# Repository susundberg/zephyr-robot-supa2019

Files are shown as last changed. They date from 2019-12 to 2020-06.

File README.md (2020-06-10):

# zephyr-robot-supa2019
Zephyr based robot

For pictures and some details see [Hackaday.io](https://hackaday.io/project/170682-lawm-mowing-robot-with-stm32-blue-pill-and-zephyr)

## Pinout

Motor related

**Motor1 - left**

| Function | Pin | Info  |
| --- | --- | --- |
| Hal input | PA12 - TIM1_ETR | (yel) |
| Motor Control A | PB12 - DOUT | (yel) -> (Pin 9 on motor) |
| Motor Control B | PB13 - DOUT | (ora) -> (Pin 8 on motor) |
| Motor PWM | PA6 - TIM3_CH1  | (red) -> (Pin 10 on motor) |
| Bumber 1 | PA11 - ISR11 | (red) |

**Motor2 - right**

| Function | Pin | Info  |
| --- | --- | ----- |
| Hal input | PA0  - TIM2_ETR  | (ora) |
| Motor Control A | PB14 - DOUT | (red) -> (Pin 9 on motor) |
| Motor Control B | PB15 - DOUT | (gre) -> (Pin 8 on motor) |
| Motor PWM | PA7  - TIM3_CH2  | (blu) |
| Bumber 2 | PA8 - ISR8 | (blue) |

**Other**

| Function | Pin | Info  |
| --- | ---  | ----- |
| UART1-TX |  PA9 | (gre) |
| UART1-RX |  PA10 | (yel) |
| Imu I2C | PB7 - I2C1_SDA | |
| Imu I2C | PB6 - I2C1_SCL | |
| Imu isr | PB5 - ISR5 | |
| UI IR RCV |  PB3 - ISR3 | |  
| UI SW1 |  PA2 - ISR2 | |
| UI SW0 |  PA1 - ISR1 | |  
| UI LD0 |  PC13 | System led + UI led 0 | 
| UI LD1 |  PC14 | UI led 1- TODO (max sink 3ma!) |

**Big motor**

| Function | Pin | Info | Notes | 
| ---  | --- | --- | --- |
| Big Enable | PB8 - TIM4_CH3 PWM  | (ora) | Now only GPIO |
| Big current meas | PA3 - ADC1-3 | | TODO NOT CONN |
| Battery volt meas| PA4 - ADC1-4 | | TODO NOT CONN |

## Motor control

Robotdyn shield: https://robotdyn.com/motor-shield-2a-l298p-2-motors-for-arduino.html

| Function | A  |  B | PWM  |
| --- | -- | -- | ---  |
| Forward | 1  | 0  |  X |
| Backward | 0  | 1  |  X |
| Force stop | 1  | 1  |  1 |
| Free roll | 0  | 0  |  0 |

## Program cable in MK1

In programmer side:
* Yellow
* Orange
* Green (GND)

## Would next time do differently:

1. Make proto PCB rather than wire mess. Even better, plan and order PCB.
1. Add reset to Bluetooth HC-05 - it seems to buffer some shit from zephyr.
1. Add external reset to other chips?
1. While blingking leds are great, they provide quite little information. Uart over bluetooth is good, not great. Super project would have android app that would be able to show some specific values -- for example uart lines in format of: DATA:<name>:value;
1. If using STM32 boards, the Nucleo boards are cheap and contain programmer. The STM32 blue pill is cheap, works, but the reset is not working well. Booting to stm32 bootloader with program makes it work (but it does not work if cpu is messed up).

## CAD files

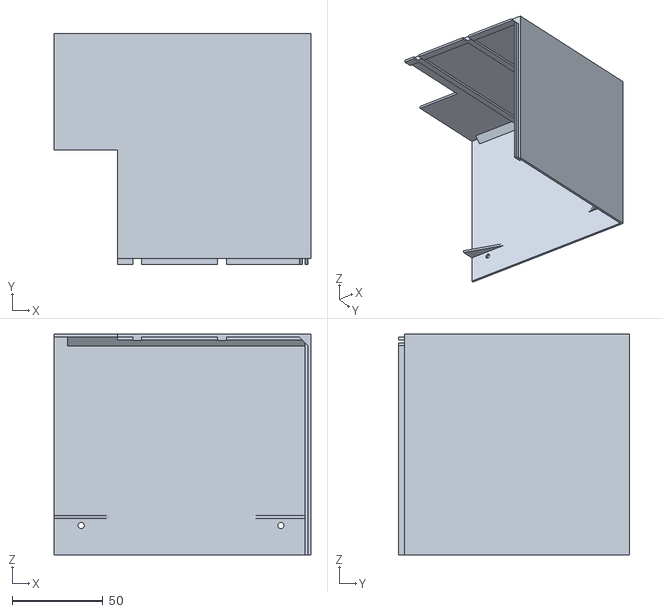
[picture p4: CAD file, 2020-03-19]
3d_parts/stl_files/rcover_ba_ri_v0.stl
141.6 x 127.3 x 121.6

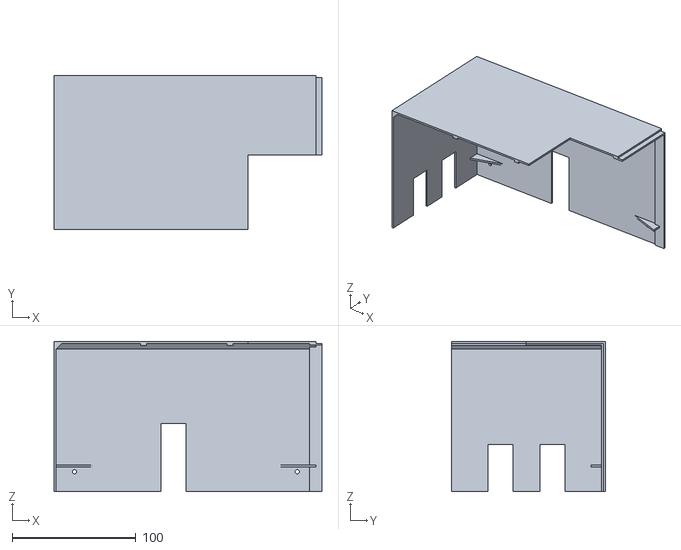
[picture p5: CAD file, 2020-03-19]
3d_parts/stl_files/rcover_fr_le_v0.stl
216.6 x 124.1 x 121.6

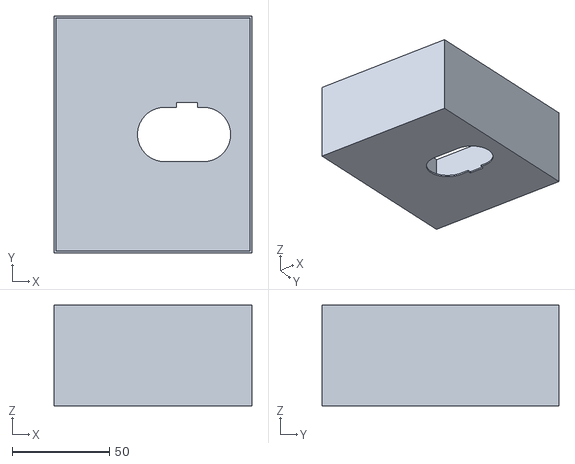
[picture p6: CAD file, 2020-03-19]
3d_parts/stl_files/rcover_bbox_v0.stl
102.0 x 122.0 x 52.0

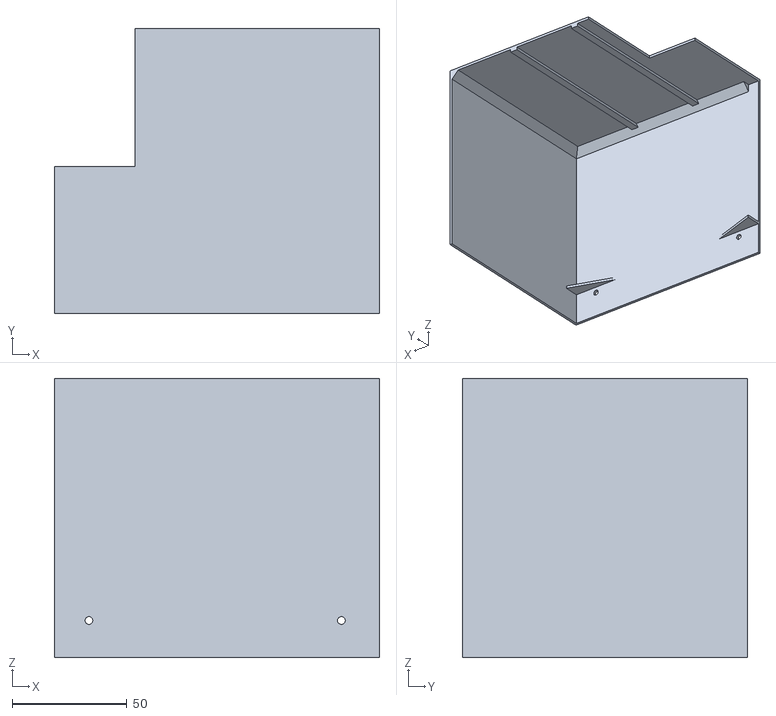
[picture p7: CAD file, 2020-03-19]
3d_parts/stl_files/rcover_ba_le_v0.stl
141.6 x 124.1 x 121.6

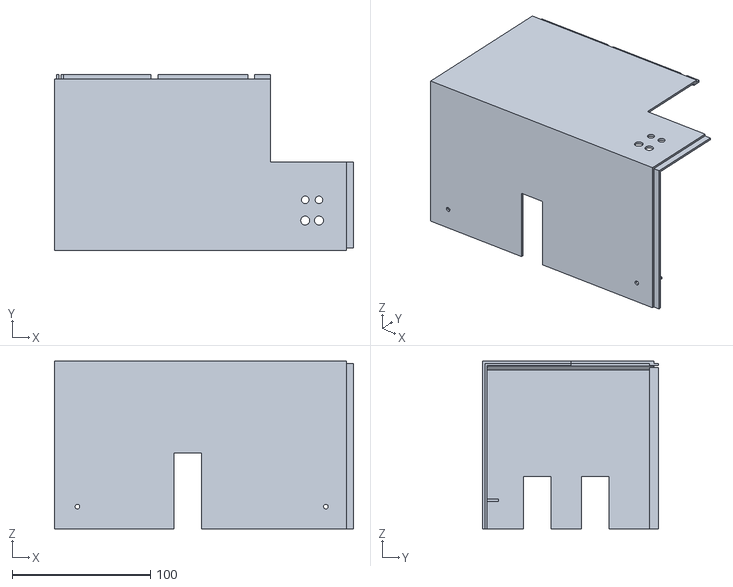
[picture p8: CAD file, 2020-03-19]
3d_parts/stl_files/rcover_fr_ri_v1.stl
216.6 x 127.3 x 121.6

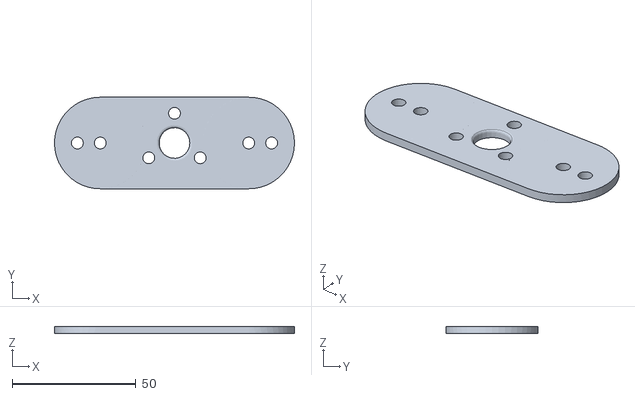
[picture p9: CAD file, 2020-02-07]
3d_parts/stl_files/robot_mower_blade_v0.stl
97.0 x 37.0 x 3.01

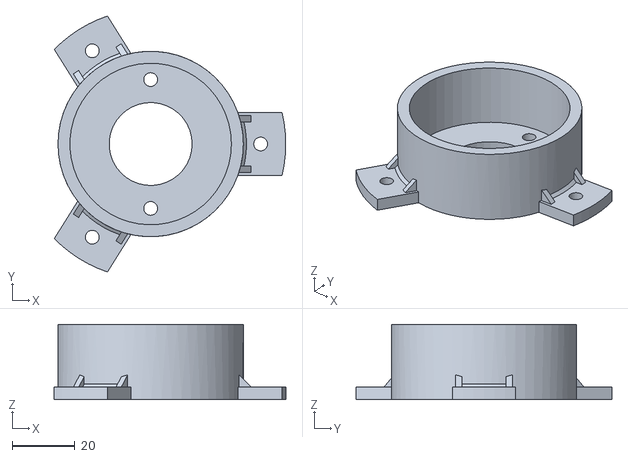
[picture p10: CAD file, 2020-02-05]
3d_parts/stl_files/bmotor_mount_v0.stl
73.7 x 81.5 x 24.0

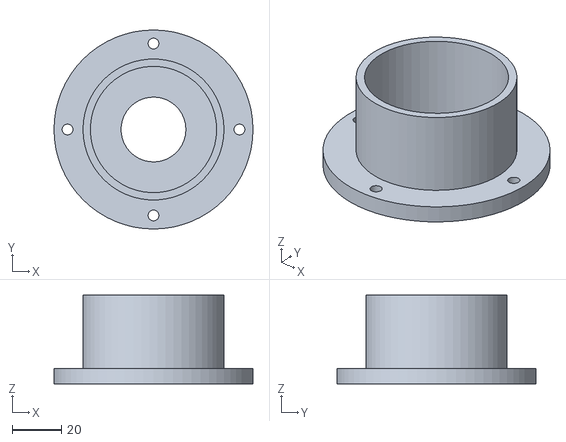
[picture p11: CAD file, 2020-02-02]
3d_parts/stl_files/robot_motor_large_v0.stl
81.0 x 81.0 x 36.2

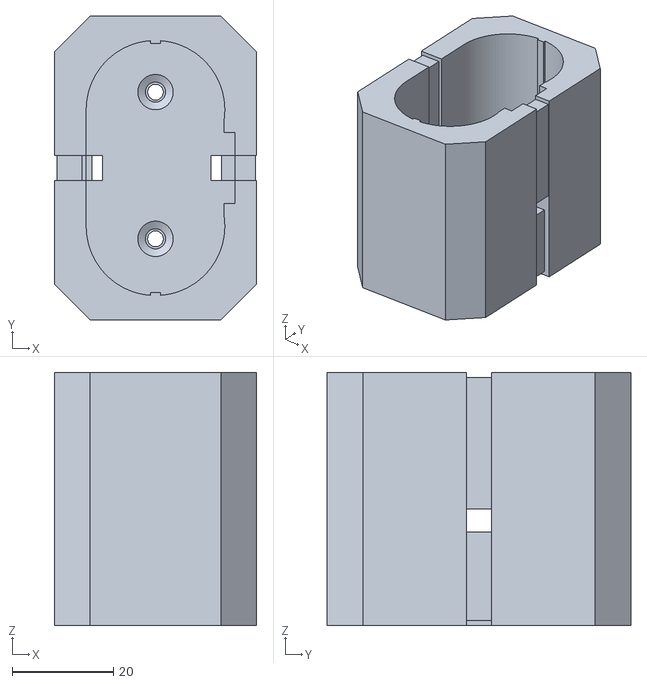
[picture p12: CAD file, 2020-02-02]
3d_parts/stl_files/makita_pa12_mount_ext.stl
40.0 x 60.0 x 50.0

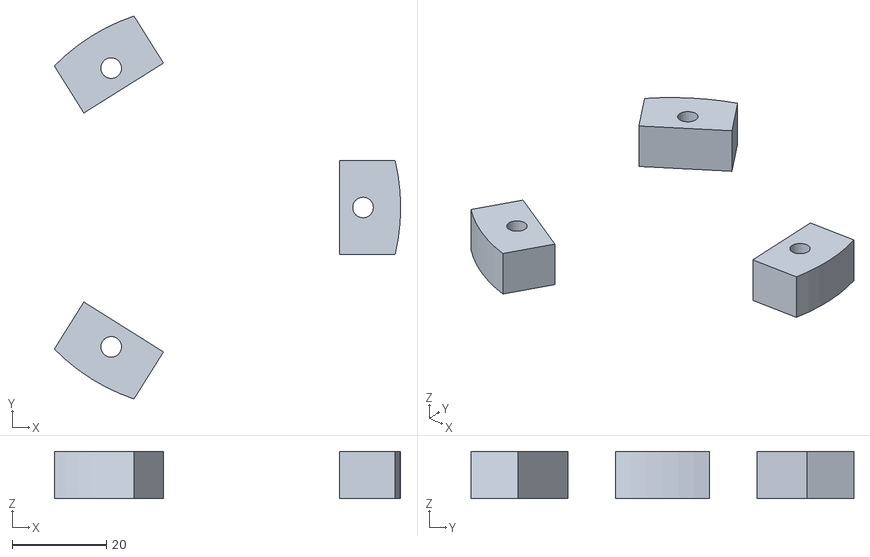
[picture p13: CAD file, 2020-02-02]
3d_parts/stl_files/bmotor_pads_wings_v0.stl
73.7 x 81.5 x 10.0

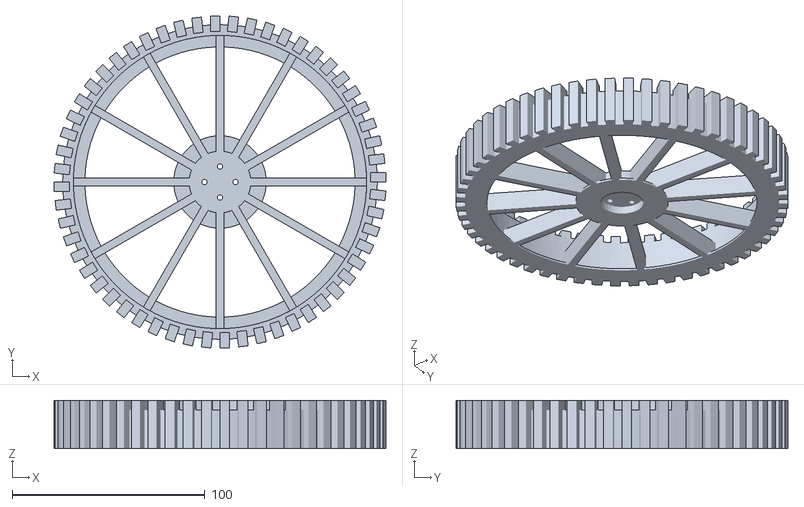
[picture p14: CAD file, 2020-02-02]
3d_parts/stl_files/wheel_v1.stl
172.0 x 172.0 x 25.0

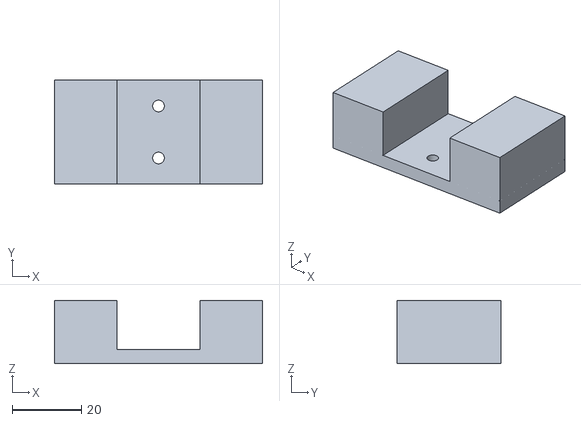
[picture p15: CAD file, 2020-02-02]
3d_parts/stl_files/robot_bumber_mount_r_v0.stl
60.0 x 30.0 x 18.2

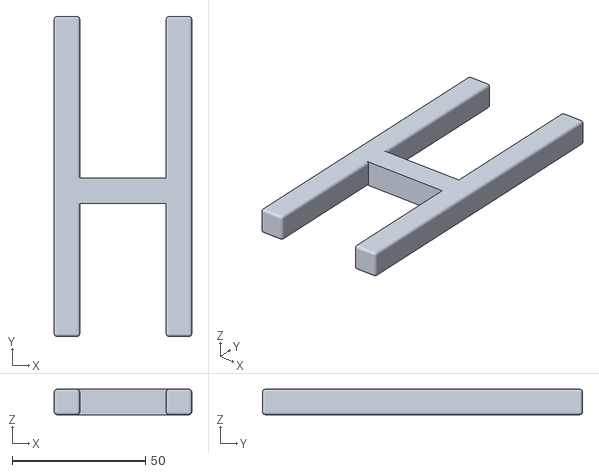
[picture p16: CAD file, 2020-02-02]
3d_parts/stl_files/robot_bumber_stick_v1.stl
51.6 x 120.0 x 9.60

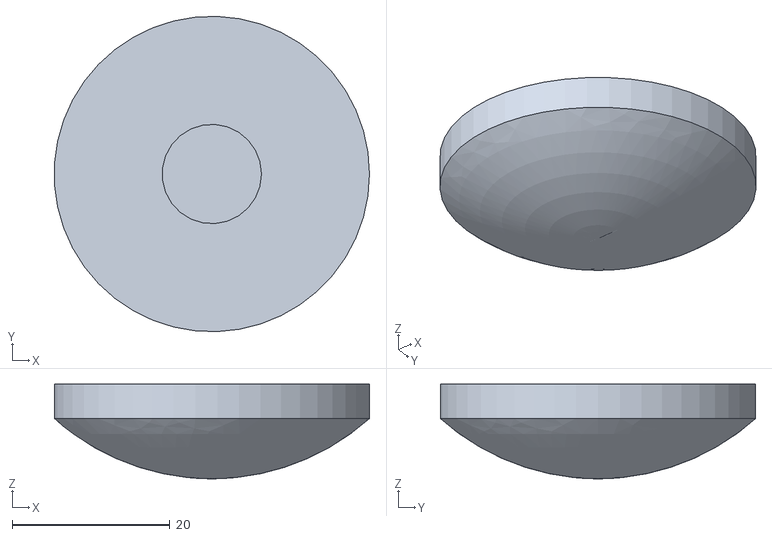
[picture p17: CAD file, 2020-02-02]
3d_parts/stl_files/robot_supp_pad_v0.stl
40.0 x 40.0 x 12.0

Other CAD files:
3d_parts/stl_files/robot_motor_small_v0.stl
3d_parts/stl_files/robot_bumber_mount_f_v0.stl
3d_parts/stl_files/robot_supp_mount_v1.stl
3d_parts/stl_files/bmotor_pads_round_v0.stl
3d_parts/stl_files/rcover_fr_ri_v0.stl
3d_parts/stl_files/robot_bumber_bumber_v0.stl
3d_parts/stl_files/robot_bumber_stick_v0.stl
3d_parts/stl_files/wheel_v0.stl

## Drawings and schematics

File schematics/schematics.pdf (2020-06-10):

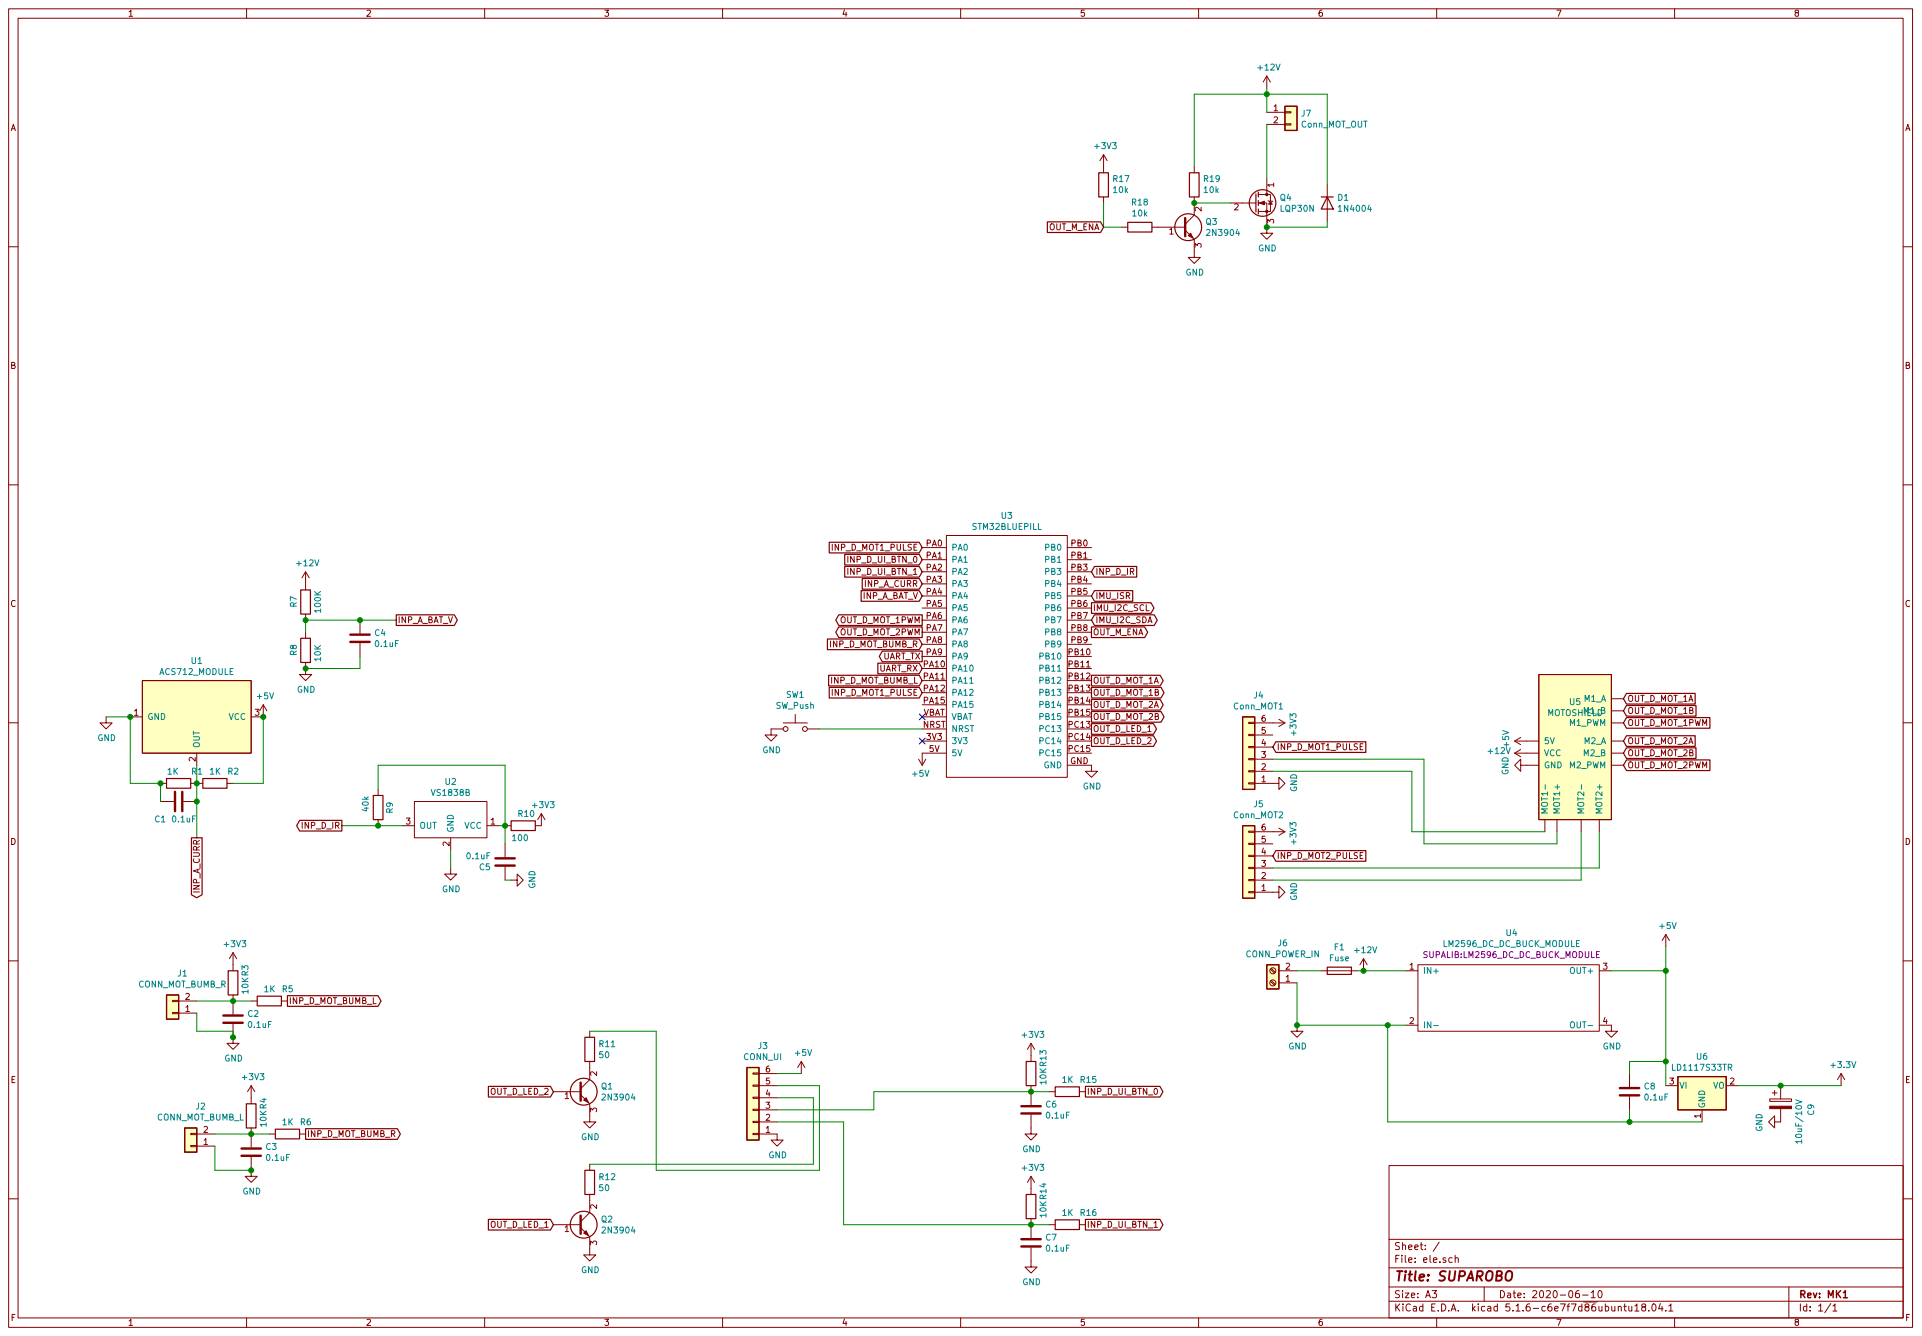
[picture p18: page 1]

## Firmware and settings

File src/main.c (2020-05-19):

/*
 * Copyright (c) 2016 Intel Corporation
 *
 * SPDX-License-Identifier: Apache-2.0
 */

/**
 * @file Sample app to demonstrate PWM.
 *
 * This app uses PWM[0].
 */


#include <stdlib.h>
#include <string.h>

#include <zephyr.h>
#include <sys/printk.h>
#include <power/reboot.h>
#include <device.h>
#include <fatal.h>
#include <init.h>


#include <drivers/pwm.h>
#include <drivers/gpio.h>

#include <logging/log.h>
#include <logging/log_ctrl.h>

#include <shell/shell.h>
#include <shell/shell_uart.h>

#define SUPA_MODULE "mai"
#include "main.h"
#include "motor/motors.h"
#include "ui/ui.h"
#include "logic/logic.h"
#include "monitor/monitor.h"
#include "utils/utils.h"
#include "utils/boot.h"

LOG_MODULE_REGISTER(app);


#define SHE_INF( fmt, ...) \
  shell_fprintf(shell, SHELL_NORMAL, fmt, ##__VA_ARGS__)

#define SHE_ERR( fmt, ...) \
  shell_fprintf(shell, SHELL_ERROR, fmt, ##__VA_ARGS__)

  
void supa_fatal_handler( const char* module, int line )
{
    printk("\nFATAL ERROR %s:%d\n", module, line );
    k_sys_fatal_error_handler(0xFFFF, NULL );
}
  
static void ircmd_move( UI_keycode code, bool repeated );
static void ircmd_function( UI_keycode code, bool repeated );
static void ircmd_auto( UI_keycode code, bool repeated );
static void ircmd_power( UI_keycode code, bool repeated );

void k_sys_fatal_error_handler(unsigned int reason, const z_arch_esf_t *esf)
{
    ARG_UNUSED(esf);
    motors_abort();
    LOG_PANIC();
    sys_reboot( SYS_REBOOT_COLD );
    CODE_UNREACHABLE;
}

#define BLINK_LED_NAME DT_GPIO_LEDS_LED_RED_LABEL
void main(void)
{
    u32_t cnt = 0;
    struct device* dev;

    monitor_init();
    
    dev = device_get_binding( DT_GPIO_LEDS_LED_RED_GPIOS_CONTROLLER );
    RET_CHECK( gpio_pin_configure( dev, DT_GPIO_LEDS_LED_RED_GPIOS_PIN, GPIO_OUTPUT | DT_GPIO_LEDS_LED_RED_GPIOS_FLAGS ) );
    
    
    ui_receiver_register( IRKEY_VOL_UP, ircmd_move );
    ui_receiver_register( IRKEY_VOL_DOWN, ircmd_move );
    ui_receiver_register( IRKEY_LEFT, ircmd_move);
    ui_receiver_register( IRKEY_RIGHT, ircmd_move );    
    ui_receiver_register( IRKEY_FUNCTION, ircmd_function );
    ui_receiver_register( IRKEY_AUTO_ON, ircmd_auto );
    ui_receiver_register( IRKEY_POWER, ircmd_power );

    ui_receiver_register( UI_SW_0, ircmd_auto );
    ui_receiver_register( UI_SW_1, ircmd_function );
    
    
    LOG_INF("Robot control task started!");
    while (1) 
    {
      gpio_pin_set(dev, DT_GPIO_LEDS_LED_RED_GPIOS_PIN, cnt % 2);
      cnt++;
      k_sleep( K_MSEC(250) );
      
      monitor_update();
    }
}



static void ircmd_move( UI_keycode code, bool repeated )
{
    float params[3] = {0};
    
    static const float MOTOR_TEST_TURN_ANGLE     = 90.0f;
    static const float MOTOR_TEST_DRIVE_DISTANCE = 20.0f;
    
    if (repeated)
        return;
    
    uint32_t opcode = 0;
    switch (code)
    {
        case IRKEY_VOL_UP:
            params[0] = MOTOR_TEST_DRIVE_DISTANCE;
            params[1] = MOTOR_TEST_DRIVE_DISTANCE;
            params[2] = MOTOR_MAX_SPEED_CM_S;
            opcode    = MOTOR_CMD_DRIVE;
            break;
        case IRKEY_VOL_DOWN:
            params[0] = -MOTOR_TEST_DRIVE_DISTANCE;
            params[1] = -MOTOR_TEST_DRIVE_DISTANCE;
            params[2] = MOTOR_MAX_SPEED_CM_S;
            opcode    = MOTOR_CMD_DRIVE;
            break;            
        case IRKEY_LEFT:
            params[0] = -MOTOR_TEST_TURN_ANGLE;
            opcode    = MOTOR_CMD_ROTATE;
            break;        
        case IRKEY_RIGHT:
            params[0] = +MOTOR_TEST_TURN_ANGLE;
            opcode    = MOTOR_CMD_ROTATE;
            break; 
        default:
            ASSERT(0);
            return;
    }
    motors_send_cmd( opcode, params, 3 );
}

static void ircmd_function( UI_keycode code, bool pressed )
{
    motors_control_function( pressed );
}

static void ircmd_power( UI_keycode code, bool pressed )
{
    if (!pressed)
        return;
    
    motors_send_cmd( MOTOR_CMD_STOP, NULL, 0 );
    motors_control_function( false ); 
       
}

static void ircmd_auto( UI_keycode code, bool pressed )
{
    if ( pressed == false )
    {
        logic_send( LOGIC_CMD_STOP );
        return;
    }
        
    if ( ui_receiver_read( UI_SW_1 ) == false )
    {
        LOG_INF("Starting LEFT version of logic");
       logic_send( LOGIC_CMD_START_LEFT );
    }
    else
    {
        LOG_INF("Starting RIGHT version of logic");
        logic_send( LOGIC_CMD_START_RIGHT );
    }
}


static int cmd_reboot(const struct shell *shell, size_t argc, char **argv)
{
    ARG_UNUSED(argc);
    ARG_UNUSED(argv);
    ARG_UNUSED(shell);
    SHE_INF("Reboot requested now!\n");
    sys_reboot( SYS_REBOOT_COLD );
    return 0;
}

static int cmd_bootloader(const struct shell *shell, size_t argc, char **argv)
{
    ARG_UNUSED(argc);
    ARG_UNUSED(argv);
    ARG_UNUSED(shell);
    SHE_INF("Reboot BOOTLOADER!\n");
    supa_bootloader_enable();
    sys_reboot( SYS_REBOOT_COLD );
    return 0;
}




static int cmd_motor_stop(const struct shell *shell, size_t argc, char **argv)
{
    ARG_UNUSED(argc);
    ARG_UNUSED(argv);
    ARG_UNUSED(shell);
    motors_send_cmd( MOTOR_CMD_STOP, NULL, 0 );
    return 0; 
}


static int cmd_motor_test(const struct shell *shell, size_t argc, char **argv)
{
    ARG_UNUSED(argc);
    ARG_UNUSED(argv);
    ARG_UNUSED(shell);

   int32_t params[3];
   
    if ( parse_i32(argv[1], &params[0]) || parse_i32(argv[2], &params[1]) || parse_i32(argv[3], &params[2] ) )
    {

        SHE_ERR("Invalid arguments.\n");
        return -EINVAL;
    }
    
    motors_send_cmd( MOTOR_CMD_TEST, params, 3 );
    return 0; 
}

static int cmd_motor_pid(const struct shell *shell, size_t argc, char **argv)
{
   int params[3];
   ARG_UNUSED(argc);
   
   if ( parse_i32(argv[1], &params[0]) || parse_i32(argv[2], &params[1]) || parse_i32(argv[3], &params[2] ) )
   {

       SHE_ERR("Invalid arguments.\n");
       return -EINVAL;
   }
   float params_flt[3] = { params[0] / 100.0f, params[1] / 100.0f, params[2] / 100.0f }; 
    
   SHE_INF("Setting PID=%d %d %d /100\n", params[0],  params[1], params[2] );
   motors_set_pid( 0, params_flt );
   motors_set_pid( 1, params_flt );
   return 0;
}


static int cmd_motor_drive(const struct shell *shell, size_t argc, char **argv)
{
   int params[3];
   ARG_UNUSED(argc);
    if ( parse_i32(argv[1], &params[0]) || parse_i32(argv[2], &params[1]) || parse_i32(argv[3], &params[2] ) )
    {

        SHE_ERR("Invalid arguments.\n");
        return -EINVAL;
    }
    float params_flt[3] = { params[0] / 10.0f, params[1] / 10.0f, params[2] / 10.0f }; 
    
    motors_send_cmd( MOTOR_CMD_DRIVE, params_flt, 3 );
    return 0; 
}

static int cmd_motor_rotate(const struct shell *shell, size_t argc, char **argv)
{
   int params[1];
   ARG_UNUSED(argc);
    if ( parse_i32(argv[1], &params[0]) )
    {

        SHE_ERR("Invalid arguments.\n");
        return -EINVAL;
    }
    float params_flt[1] = { params[0] / 10.0f }; 
    
    motors_send_cmd( MOTOR_CMD_ROTATE, params_flt, 1 );
    return 0; 
}

static int cmd_test_ui(const struct shell *shell, size_t argc, char **argv)
{
   int params[1];
   ARG_UNUSED(argc);
    if ( parse_i32(argv[1], &params[0]) )
    {

        SHE_ERR("Invalid arguments.\n");
        return -EINVAL;
    }
    LOG_INF("Set UI state x%02X", params[0] );
    ui_signal_state( params[0] );
    return 0; 
}


SYS_INIT( supa_bootloader_check, PRE_KERNEL_1, 0 );

SHELL_STATIC_SUBCMD_SET_CREATE(sub_pwm,
        SHELL_CMD_ARG(drive, NULL, "drive <dist_left mm> <dist_right mm> <speed mm/sec>", cmd_motor_drive, 4, 0 ),
        SHELL_CMD_ARG(rot, NULL, "rotate <angle>", cmd_motor_rotate, 2, 0 ),
        SHELL_CMD_ARG(stop, NULL, "stop <>", cmd_motor_stop, 1, 0 ),
        SHELL_CMD_ARG(pid, NULL, "pid <>", cmd_motor_pid, 4, 0 ),                       
        SHELL_CMD_ARG(test, NULL, "test <time_ramp_sec> <time_const_sec> <max_speed cm/sec>", cmd_motor_test, 4, 0 ),
        SHELL_SUBCMD_SET_END
);
/* Creating root (level 0) command "demo" */
SHELL_CMD_REGISTER(motor, &sub_pwm, "MOTOR commands", NULL);
SHELL_CMD_ARG_REGISTER(reset, NULL, "RESTART system", cmd_reboot, 0, 0);
SHELL_CMD_ARG_REGISTER(bootloader, NULL, "REBOOT system to bootloader", cmd_bootloader, 0, 0);
SHELL_CMD_ARG_REGISTER(test_ui, NULL, "TEST_UIsystem", cmd_test_ui, 2, 0);

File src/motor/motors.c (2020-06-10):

#include <zephyr.h>
#include <math.h>

#include <drivers/gpio.h>
#include <logging/log.h>

#define SUPA_MODULE "mom"

#include "../main.h"
#include "motors.h"
#include "motor_ramp.h"
#include "motor_timers.h"
#include "../pid/pid.h"

LOG_MODULE_REGISTER(motor);


typedef struct
{
  int32_t         params[3];
  Motor_cmd_type  opcode; 
} Motor_cmd;

typedef enum
{
    MOTOR_STATUS_IDLE,
    MOTOR_STATUS_DRIVE,
} Motor_state;


#define LOCAL_queue_size 8
static Motor_cmd __aligned(4) LOCAL_queue_buffer[ LOCAL_queue_size ];
static struct k_msgq LOCAL_queue;

static Motor_cmd_done_callback LOCAL_motor_callback = NULL;

#define MOTOR_CONTROL_LOOP_MS 10
static const float MOTOR_CONTROL_LOOP_DT_S = MOTOR_CONTROL_LOOP_MS / 1000.0f;
#define MOTOR_PWM_SANITY_CHECK_LIMIT 6000

static PidController LOCAL_pid[2];


void motors_pid_init()
{
    // Measured by trial and error
   static const float PID_COEFFS[3] = { 30.0f, 60.0f, 0.4f };
   
   for ( int loop = 0; loop < 2; loop ++ )
   {
       pid_control_setup( &LOCAL_pid[loop], PID_COEFFS[0], PID_COEFFS[1], PID_COEFFS[2], MOTOR_CONTROL_LOOP_DT_S );
   }
}

void motors_set_pid( int motor, const float* coeff )
{
    LOCAL_pid[motor].coeff_p = coeff[0];
    LOCAL_pid[motor].coeff_i = coeff[1];
    LOCAL_pid[motor].coeff_d = coeff[2];
    
}

void motors_set_callback( Motor_cmd_done_callback callback )
{
    if ( callback != NULL )
    {
       ASSERT( LOCAL_motor_callback == NULL );
    }
    LOCAL_motor_callback = callback ;
}

void motors_send_cmd( uint32_t opcode, void* params, uint32_t nparams )
{

    Motor_cmd cmd; 
    ASSERT_ISR( sizeof(float) == sizeof(uint32_t) );
    ASSERT_ISR( nparams <= MOTOR_MAX_PARAMS );
    
    memset( &cmd, 0x00, sizeof(cmd));

    cmd.opcode = opcode;
    memcpy( cmd.params, params, sizeof(uint32_t)*nparams );
    
    ASSERT_ISR( k_msgq_put( &LOCAL_queue, &cmd, K_NO_WAIT ) == 0 );
}

static const Motor_cmd* motor_queue_get( k_timeout_t wait_time )
{
   static Motor_cmd cmd;
   
   while (1)
   {
       int ret = k_msgq_get(&LOCAL_queue, &cmd, wait_time );
      if (  ret == 0 )
          return &cmd;
      
      if ( ret == -ENOMSG )
          continue;
      
      return NULL;
   }   
}


void motors_abort()
{
    motor_timers_abort();
}

static void motor_cmd_stop( const Motor_cmd* cmd )
{
    (void)(cmd);
    motor_control_disable_all();
}


static void drive_time_start( s64_t* timer )
{
    *timer = k_uptime_get();
}

static float drive_time_get( const s64_t* timer )
{
    s64_t tmp = *timer;
    s64_t milliseconds_spent = k_uptime_delta(&tmp);
    return milliseconds_spent/1000.0f;
}


#include <stdio.h>

static void motor_cmd_test( const Motor_cmd* cmd )
{
    s64_t drive_start_ticks; 
    
    float position_cm[2];
    float pos_old[2] = { 0.0f, 0.0f };
    motor_timers_set_location_zero( position_cm );
    
    
    drive_time_start( &drive_start_ticks );
    
    float const_start = cmd->params[0];
    float const_stop  = const_start + cmd->params[1];
    float all_done    = const_stop + cmd->params[0];
    
    
    float const_speed = cmd->params[2];
    float acc_ramp = cmd->params[2] / cmd->params[0];
    
    LOG_INF("Acceleration ramp %d s  const %d s  -> const speed: %d cm/sec acc: %d cm/sec^2", 
            ROUND_INT(const_start), ROUND_INT(const_stop - const_start),  ROUND_INT(const_speed), ROUND_INT(acc_ramp) );

    const float time_diff_sec = 0.1;
    
    for ( int loop = 0; loop < 2; loop ++ )
       motor_control_enable( loop, false );
    
    while(1)
    {
        
        // Get new location
        float time_sec = drive_time_get( &drive_start_ticks ); 
        float speed_target;
        float speed_obs[2];
        
        if ( time_sec < const_start )
        {
            speed_target = time_sec * acc_ramp;
        }
        else if ( time_sec >= const_start && time_sec < const_stop )
        {
            speed_target = const_speed;
        }
        else if ( time_sec >= const_stop && time_sec < all_done )
        {
            float ramp_time = time_sec  - const_stop;
            speed_target = const_speed - ramp_time*acc_ramp;
        }
        else
        {
            LOG_INF("Motor test ramp done, bail out!");
            break;
        }
        
        uint32_t motor_pwm[2];
        
        for ( int loop = 0; loop < 2; loop ++ )
        {
           motor_pwm[loop] = motor_timers_set_speed( loop, speed_target*25.0f );
        }

        k_sleep( K_MSEC( time_diff_sec * 1000 ) );
        
        
        motor_timers_get_location( position_cm );
        
        for ( int loop = 0; loop < 2; loop ++ )
           speed_obs[loop] = ( position_cm[loop]  - pos_old[loop] ) / time_diff_sec;
        
        memcpy( pos_old, position_cm, sizeof(float)*2 );
        
        printf("T=%0.1f - pos: %0.1f %0.1f -- speed: %0.1f %0.1f - target: %0.1f - pwm %d %d\n", 
               (double)time_sec, (double)position_cm[0], (double)position_cm[1], (double)speed_obs[0], (double)speed_obs[1], 
               (double)speed_target, motor_pwm[0], motor_pwm[1] ); 
    }
    
    motor_cmd_stop(NULL);
    motor_timers_get_location( position_cm );
    LOG_INF("Final position: %d %d", ROUND_INT( position_cm[0] ), ROUND_INT( position_cm[1])  ); 
     
}
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

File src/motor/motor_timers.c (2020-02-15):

#include <stm32f1xx_hal.h>
#include <stm32f1xx_hal_conf.h>


#define SUPA_MODULE "mot"

#include "motors.h"


static TIM_HandleTypeDef LOCAL_tim_pwm;
static TIM_HandleTypeDef LOCAL_tim_left;
static TIM_HandleTypeDef LOCAL_tim_right;

#define PWM_TIM_PERIOD_CYCLES 1000



LOG_MODULE_REGISTER( motor_tim );


static const uint32_t LOCAL_pwm_channels[2] = { TIM_CHANNEL_1, TIM_CHANNEL_2 };

/* TIM2 init function */
static void tim_pwm_init(void)
{
  TIM_ClockConfigTypeDef sClockSourceConfig = {0};
  TIM_OC_InitTypeDef sConfigOC = {0};

  __HAL_RCC_TIM3_CLK_ENABLE();
  
  LOCAL_tim_pwm.Instance = TIM3; 
  LOCAL_tim_pwm.Init.Prescaler     = (CONFIG_SYS_CLOCK_HW_CYCLES_PER_SEC / 200000) - 1; // 500 -> 200 khz
  LOCAL_tim_pwm.Init.CounterMode   = TIM_COUNTERMODE_UP;
  LOCAL_tim_pwm.Init.Period        = PWM_TIM_PERIOD_CYCLES;
  LOCAL_tim_pwm.Init.ClockDivision = TIM_CLOCKDIVISION_DIV1;
  LOCAL_tim_pwm.Init.AutoReloadPreload = TIM_AUTORELOAD_PRELOAD_DISABLE;
  HAL_CHECK (HAL_TIM_Base_Init(&LOCAL_tim_pwm) );

  sClockSourceConfig.ClockSource = TIM_CLOCKSOURCE_INTERNAL;
  HAL_CHECK (HAL_TIM_ConfigClockSource(&LOCAL_tim_pwm, &sClockSourceConfig) );
  HAL_CHECK (HAL_TIM_PWM_Init(&LOCAL_tim_pwm) );
 
  sConfigOC.OCMode = TIM_OCMODE_PWM1;
  sConfigOC.Pulse = 0;
  sConfigOC.OCPolarity = TIM_OCPOLARITY_HIGH;
  sConfigOC.OCFastMode = TIM_OCFAST_DISABLE;
  
  for ( int loop = 0; loop < 2; loop ++ )
  {
     HAL_CHECK( HAL_TIM_PWM_ConfigChannel(&LOCAL_tim_pwm, &sConfigOC, LOCAL_pwm_channels[ loop ] ) );
     HAL_CHECK( HAL_TIM_PWM_Start( &LOCAL_tim_pwm, LOCAL_pwm_channels[ loop ] ) );   
  }
}



/* TIM3 init function */
static void tim_counter_init(void)
{
  TIM_ClockConfigTypeDef sClockSourceConfig = {0};

  
  __HAL_RCC_TIM1_CLK_ENABLE();
  __HAL_RCC_TIM2_CLK_ENABLE();
  
  
  LOCAL_tim_left.Instance = TIM1;
  LOCAL_tim_left.Init.Prescaler = 0;
  LOCAL_tim_left.Init.CounterMode = TIM_COUNTERMODE_UP;
  LOCAL_tim_left.Init.Period = 0xFFFF;
  LOCAL_tim_left.Init.ClockDivision = TIM_CLOCKDIVISION_DIV1;
  LOCAL_tim_left.Init.AutoReloadPreload = TIM_AUTORELOAD_PRELOAD_DISABLE;
  
  LOCAL_tim_right.Instance = TIM2;
  LOCAL_tim_right.Init = LOCAL_tim_left.Init;
  
  HAL_CHECK( HAL_TIM_Base_Init(&LOCAL_tim_left) );
  HAL_CHECK( HAL_TIM_Base_Init(&LOCAL_tim_right) );
  
  
  sClockSourceConfig.ClockSource = TIM_CLOCKSOURCE_ETRMODE2;
  sClockSourceConfig.ClockPolarity = TIM_CLOCKPOLARITY_NONINVERTED;
  sClockSourceConfig.ClockPrescaler = TIM_CLOCKPRESCALER_DIV1;
  sClockSourceConfig.ClockFilter = 0;
  
  HAL_CHECK (HAL_TIM_ConfigClockSource(&LOCAL_tim_left, &sClockSourceConfig));
  HAL_CHECK (HAL_TIM_ConfigClockSource(&LOCAL_tim_right, &sClockSourceConfig));
  

  HAL_CHECK( HAL_TIM_Base_Start(&LOCAL_tim_left) );
  HAL_CHECK( HAL_TIM_Base_Start(&LOCAL_tim_right) );
}


static void pos_get( uint32_t* pos )
{
    pos[0] = __HAL_TIM_GET_COUNTER( &LOCAL_tim_left );
    pos[1] = __HAL_TIM_GET_COUNTER( &LOCAL_tim_right );
    
}

uint32_t LOCAL_offset[2];


void motor_timers_abort()
{
  HAL_CHECK( HAL_TIM_Base_Stop(&LOCAL_tim_pwm) ); 
}


uint32_t motor_timers_set_speed( uint32_t motor, int pwm_target )
{
 
   
   if UNLIKELY( pwm_target <= MOTOR_PWM_OFFSET )
   {
       pwm_target = 0;
   }
   else
   {
        if UNLIKELY( pwm_target >= PWM_TIM_PERIOD_CYCLES ) 
        {
            pwm_target = PWM_TIM_PERIOD_CYCLES;
        }

   }

   ASSERT( motor < 2 );
   __HAL_TIM_SET_COMPARE( &LOCAL_tim_pwm, LOCAL_pwm_channels[ motor ], pwm_target );
   return pwm_target;
}


void motor_timers_get_location( float* pos )
{
     uint32_t tim_now[2];
     
     pos_get( tim_now );
     
     for ( int loop = 0; loop < 2; loop ++ )
     {
        uint32_t count_add;

        
        if ( tim_now[loop] < LOCAL_offset[loop] )
        {
            count_add = tim_now[loop] + (0xFFFF - LOCAL_offset[loop]);
        }
        else // tim_now >= local_offset
        {
            count_add = tim_now[loop] - LOCAL_offset[loop];
        }
        
        LOCAL_offset[loop] = tim_now[loop];    
        pos[loop] += (count_add * MOTOR_TICKS_TO_CM);
     }
}

void motor_timers_set_location_zero( float* pos )
{
    pos_get( LOCAL_offset );
    pos[0] = 0.0f;
    pos[1] = 0.0f;
}



void motor_timers_init()
{
    tim_pwm_init();
    tim_counter_init();
    LOG_INF("Motor timers init done");
}

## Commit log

2019-12-20 This version has two PWM outputs from console commands
2020-01-14 Initial motor task
2020-01-20 Minor updates, last with STM32F4 family
2020-01-30 This version works great on stm32_min_dev board
2020-01-31 Bumbers and function button support
2020-02-02 Add stl-models
    [bmotor_mount_v0.stl, bmotor_pads_round_v0.stl, bmotor_pads_wings_v0.stl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]
2020-02-05 More robot parts
    [bmotor_mount_v0.stl, robot_mower_blade_v0.stl]
2020-02-07 Modify parts
    [robot_mower_blade_v0.stl]
2020-02-14 * Motor tuning for better performance * Add double promotion warning * Update the pin api * Logic module
2020-02-14 Initial pid test
2020-02-28 PID control seems to work
2020-03-19 UPD: Update big motor control pin
    [rcover_ba_le_v0.stl, rcover_ba_ri_v0.stl, rcover_bbox_v0.stl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]
2020-03-23 CLEAR: Remove pid prints and increase the pid cutoff limit
2020-04-17 ADD support for UI-button switch and refactor IR-receiver. IR-receiver code to be fully-tested.
2020-04-29 UPD: Update to latest Zephyr master FEAT: Add UI-status leds better to inform what stopped cutting FIX: Fix motor pulses to cm ration
    [logic.c, main.c, motors.c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]
2020-05-18 FEAT: Monitor adc values for battery / current
2020-05-19 FEAT: Simplify logic and add left/right variants FIX: adc current measurement values
    [logic.c, main.c, monitor.c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]
2020-06-10 Move stuck detection to CM rather than PWM related
    [logic.c, motors.c, motors.h]
2020-06-10 Move to idle when stop issued ad stopped
    [logic.c]
2020-06-10 3D: Lawn detect sensor
2020-06-10 FEAT: Added lawn detect sensor (that does not work very well..)
    [logic.c, monitor.c, motors.h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]
2020-06-10 FEAT: Add initial schematics (based on what might have been done)
    [TMP.sch, ele.kicad_pcb, ele.sch]
